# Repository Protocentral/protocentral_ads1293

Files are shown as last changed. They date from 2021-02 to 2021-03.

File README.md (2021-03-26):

ProtoCentral ADS1293 breakout board
================================
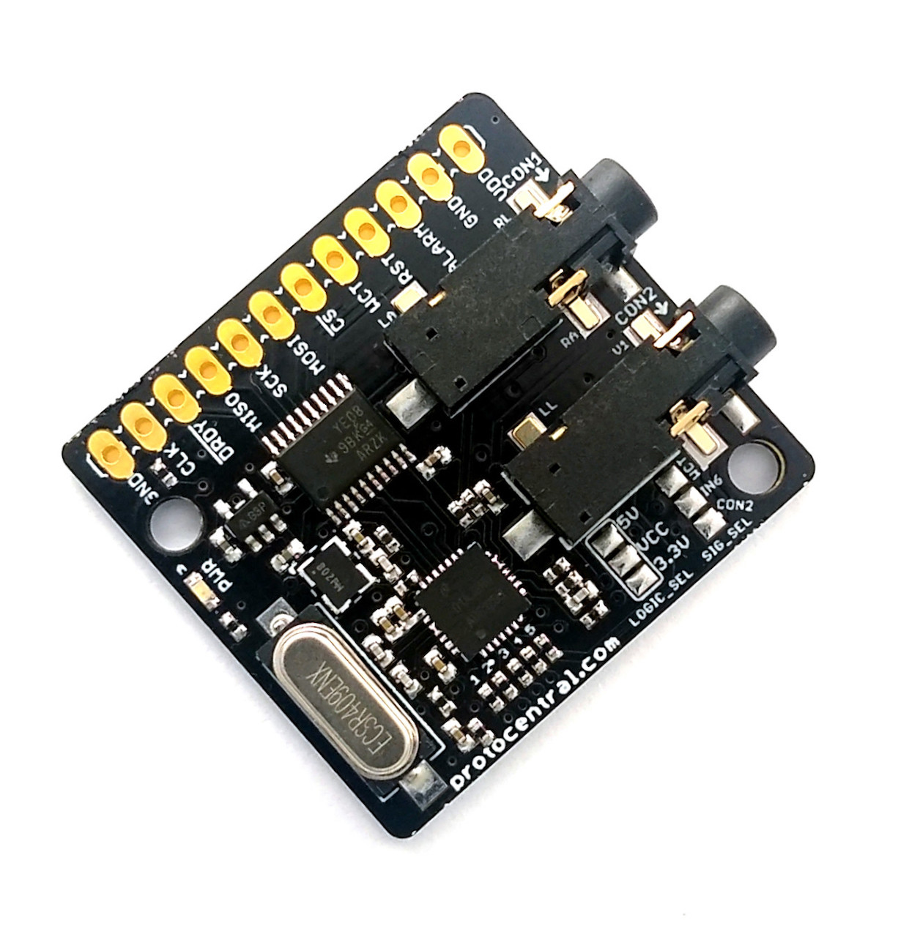
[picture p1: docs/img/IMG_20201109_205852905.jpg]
ADS1293 Breakout


If you don't already have one, you can BUY [ProtoCentral ADS1293 Breakout here.](https://protocentral.com/product/protocentral-ads1293-breakout-board/)

Are you looking for a small ECG board that can read your heart? Well, here it is!!! The ADS1293 breakout board has a capacity of 3 channels and the integration of 4 leads  of the electrical activity of the heart. This is a simple board to connect ECG to your Arduino, Raspberry Pi or any microcontroller you like.

This breakout board for the TI ADS1293 Analog front-end IC comes with with three High-Resolution Digital ECG Channels With Simultaneous PACE Output. 

Features
--------
* ADS1293 Analog Front End IC.
* Three High-Resolution Digital ECG Channels.
* Low Power: 0.3 mW/channel.
* Onboard 3.3V voltage regulator for low noise.
* Onboard logic level translators for Arduino interface.
* Prototyping area for adding additional components.

Includes
--------
* ADS1293 Breakout Board
* 2x Electrode cables with 3.5mm connector
* Pack of disposable stick-on ECG electrodes-20 each

## Wiring to your Arduino

|ADS1293 Pin | Pin Function |Arduino Uno Pin Connection|
|---|:---:|---:|
| DRDY | Data ready Output pin|  D2 | 
| MISO | Slave Out |  D12 |
| MOSI | Slave In |  D11 |
| SCLK | Serial Clock |  D13 |
| CS | Chip Select |  D10 |
| vcc | Digital VDD |  +5V |
| GND | Digital Gnd |  Gnd |

## Running the Arduino Sketch
If you have correctly installed the libraries, the example sketeches should now be available from within Arduino.
If its not showing, please, [Download the Arduino Sketch from our repository here](https://github.com/Protocentral/protocentral-ads1293-arduino) and place it in the arduino libraries folder.

Open up your Arduino IDE and run the Arudino sketch (.ino) file in the archive that you downloaded. Your Arduino should now be programmed to read the ecg data and sending over the USB-UART.

## Using the ProtoCentral OpenView GUI
The GUI for visualizing the ads1293 data is written in Processing, based on Java and is cross-compilable across platforms.

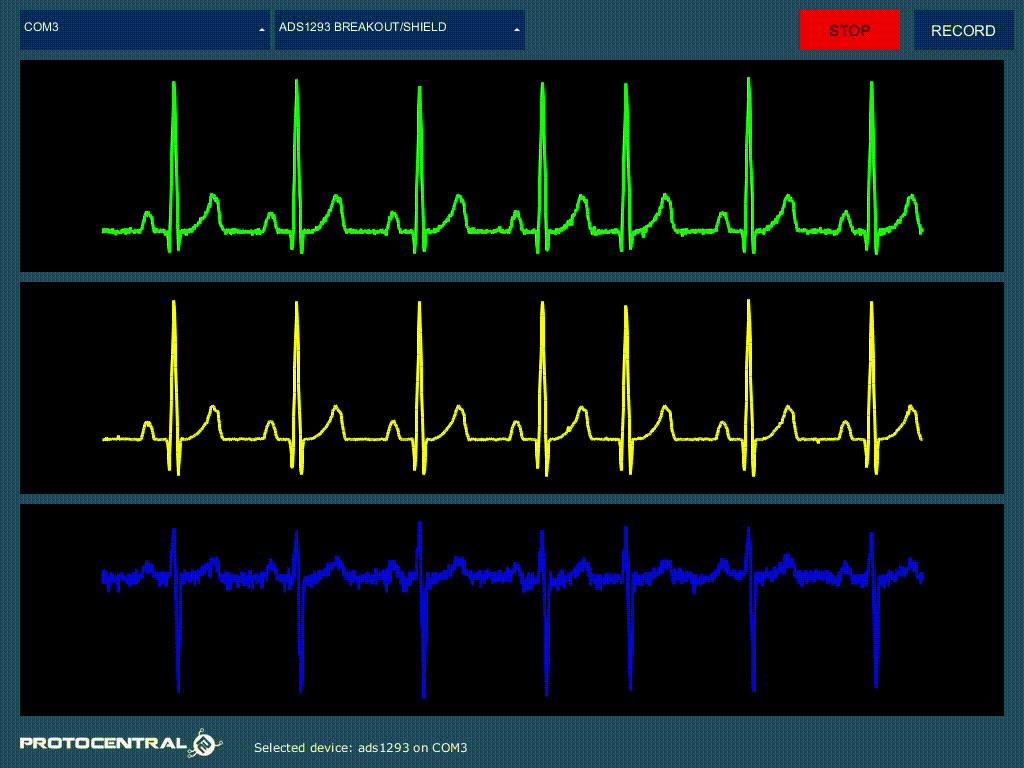
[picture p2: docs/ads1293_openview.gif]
Wearing the Electrode


Java 8 is required on all platforms for running the processing-based GUI application. You can download Java for your platform from the Official Java website.

You can download and install ProtoCentral OpenView from here: https://github.com/Protocentral/protocentral_openview

License Information
===================

ADS1220 Breakout

This product is open source! Both, our hardware and software are open source and licensed under the following licenses:

Hardware
---------

**All hardware is released under the [CERN-OHL-P v2](https://ohwr.org/cern_ohl_p_v2.txt)** license.

Copyright CERN 2020.

This source describes Open Hardware and is licensed under the CERN-OHL-P v2.

You may redistribute and modify this documentation and make products
using it under the terms of the CERN-OHL-P v2 (https:/cern.ch/cern-ohl).
This documentation is distributed WITHOUT ANY EXPRESS OR IMPLIED
WARRANTY, INCLUDING OF MERCHANTABILITY, SATISFACTORY QUALITY
AND FITNESS FOR A PARTICULAR PURPOSE. Please see the CERN-OHL-P v2
for applicable conditions

Software
--------

**All software is released under the MIT License(http://opensource.org/licenses/MIT).**

THE SOFTWARE IS PROVIDED "AS IS", WITHOUT WARRANTY OF ANY KIND, EXPRESS OR IMPLIED, INCLUDING BUT NOT LIMITED TO THE WARRANTIES OF MERCHANTABILITY, FITNESS FOR A PARTICULAR PURPOSE AND NONINFRINGEMENT. IN NO EVENT SHALL THE AUTHORS OR COPYRIGHT HOLDERS BE LIABLE FOR ANY CLAIM, DAMAGES OR OTHER LIABILITY, WHETHER IN AN ACTION OF CONTRACT, TORT OR OTHERWISE, ARISING FROM, OUT OF OR IN CONNECTION WITH THE SOFTWARE OR THE USE OR OTHER DEALINGS IN THE SOFTWARE.

Documentation
-------------
**All documentation is released under [Creative Commons Share-alike 4.0 International](http://creativecommons.org/licenses/by-sa/4.0/).**


You are free to:

* Share — copy and redistribute the material in any medium or format
* Adapt — remix, transform, and build upon the material for any purpose, even commercially.
The licensor cannot revoke these freedoms as long as you follow the license terms.

Under the following terms:

* Attribution — You must give appropriate credit, provide a link to the license, and indicate if changes were made. You may do so in any reasonable manner, but not in any way that suggests the licensor endorses you or your use.
* ShareAlike — If you remix, transform, or build upon the material, you must distribute your contributions under the same license as the original.

Please check [*LICENSE.md*](LICENSE.md) for detailed license descriptions.

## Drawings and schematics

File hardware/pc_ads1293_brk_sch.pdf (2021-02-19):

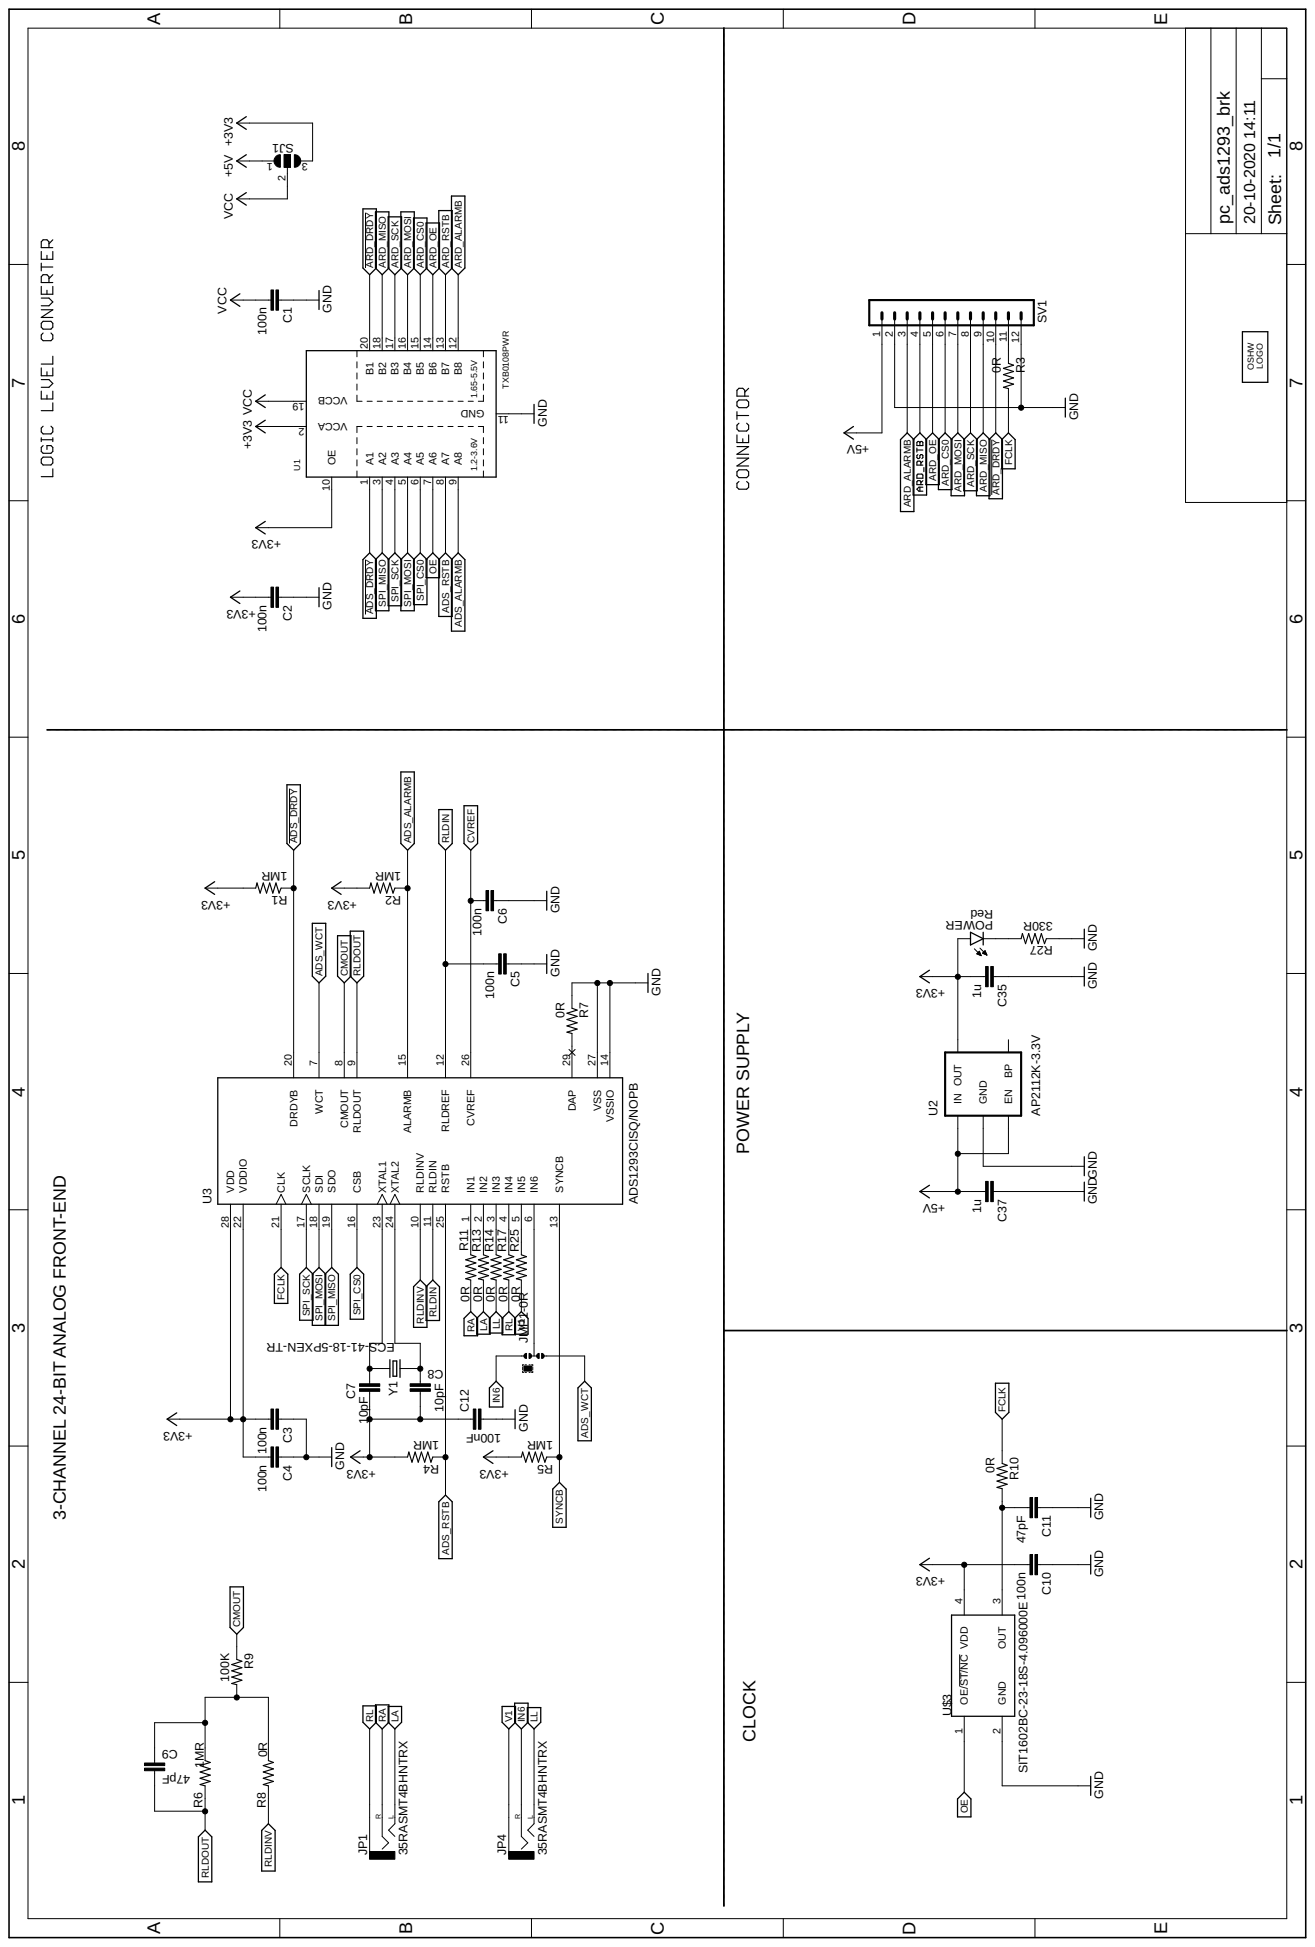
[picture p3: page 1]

1.2-3.6V 1.65-5.5V GND GND 3V3+ GND 1u 1uGND V5+ R033 de R GND V5+ TXB0108PWR +3V3GND 3V3+ 100nGND 100 3V3+ nGND +5V +3V3 VCC VCC VCC AP2112K-3.3V ADS1293CISQ/NOPB 100n 100nGND 3V3+ RM1 RM1 3V3+ 3V3+ 35RASMT4BHNTRX 35RASMT4BHNTRX 100nGND 100nGND GND RM1 RM1 3V3+ 3V3+ RT- NEXP5- 81- 14- SCE 10pF10pF GND 1MR0R Fp74 100K SIT1602BC-23-18S-4.096000E 3V3+ 100nGND GND 47pFGND 0R0R0R0R0R Fn001 0R 0R 0R POWER SUPPLY CLOCK 3-CHANNEL 24-BIT ANALOG FRONT-END C35 C37 72 R RE WOP 123456789101112 SV1 ACCV 2 A1 1 A2 3 A3 4 A4 5 A5 6 A6 7 A7 8 A8 9 DNG 11 BCCV 91 B1 20 B2 18 B3 17 B4 16 B5 15 B6 14 B7 13 B8 12 OE 10 U1 C1 C2 1 3 2 1J S INGN OD UT EN BP U2 IN1 1 WCT 7 CMOUT 8 RLDOUT 9 RLDINV 10 RLDIN 11 SYNCB 13 RLDREF 12 VSSIO 14 ALARMB 15 CSB 16 SCLK 17 SDI 18 SDO 19 DRDYB 20 VDDIO 22 CLK 21 XTAL1 23 RSTB 25 XTAL2 24 CVREF 26 VSS 27 VDD 28 DAP 29 IN2 2 IN3 3 IN4 4 IN5 5 IN6 6 U3 C3 C4 1 R 2 R JP1 JP4 C5 C6 4 R 5 R Y1 C7 8 C R6 R8 9 C R9 OE/ST/NC 1 GND 2 OUT 3 VDD 4 U$3 C10 C11 R11 R13 R14 R17 R25 C12 R7 JMP1-0R R3 R10 ADS_DRDY ADS_DRDY SPI_MISO SPI_MISO SPI_SCK SPI_SCK SPI_MOSI SPI_MOSI SPI_CS0 SPI_CS0 ADS_RSTB ADS_RSTB ADS_WCT ADS_WCT ARD_MOSI ARD_MOSI ARD_MISO ARD_MISO ARD_SCK ARD_SCK ARD_CS0 ARD_CS0 ARD_DRDY ARD_DRDY FCLK FCLK FCLK ADS_ALARMB ADS_ALARMB CVREF RA RA LA LA LL LL RL RL V1 V1 SYNCB RLDINV RLDINV RLDIN RLDIN RLDOUT RLDOUT CMOUT CMOUT ARD_RSTB ARD_ALARMB ARD_ALARMB IN6 IN6 OE OE ARD_OE ARD_OE OSHW LOGO Sheet: ABCDE 1 2 3 4 5 6 7 8 ABCDE 1 2 3 4 5 6 7 8 pc_ads1293_brk 20-10-2020 14:11 1/1 RLRL

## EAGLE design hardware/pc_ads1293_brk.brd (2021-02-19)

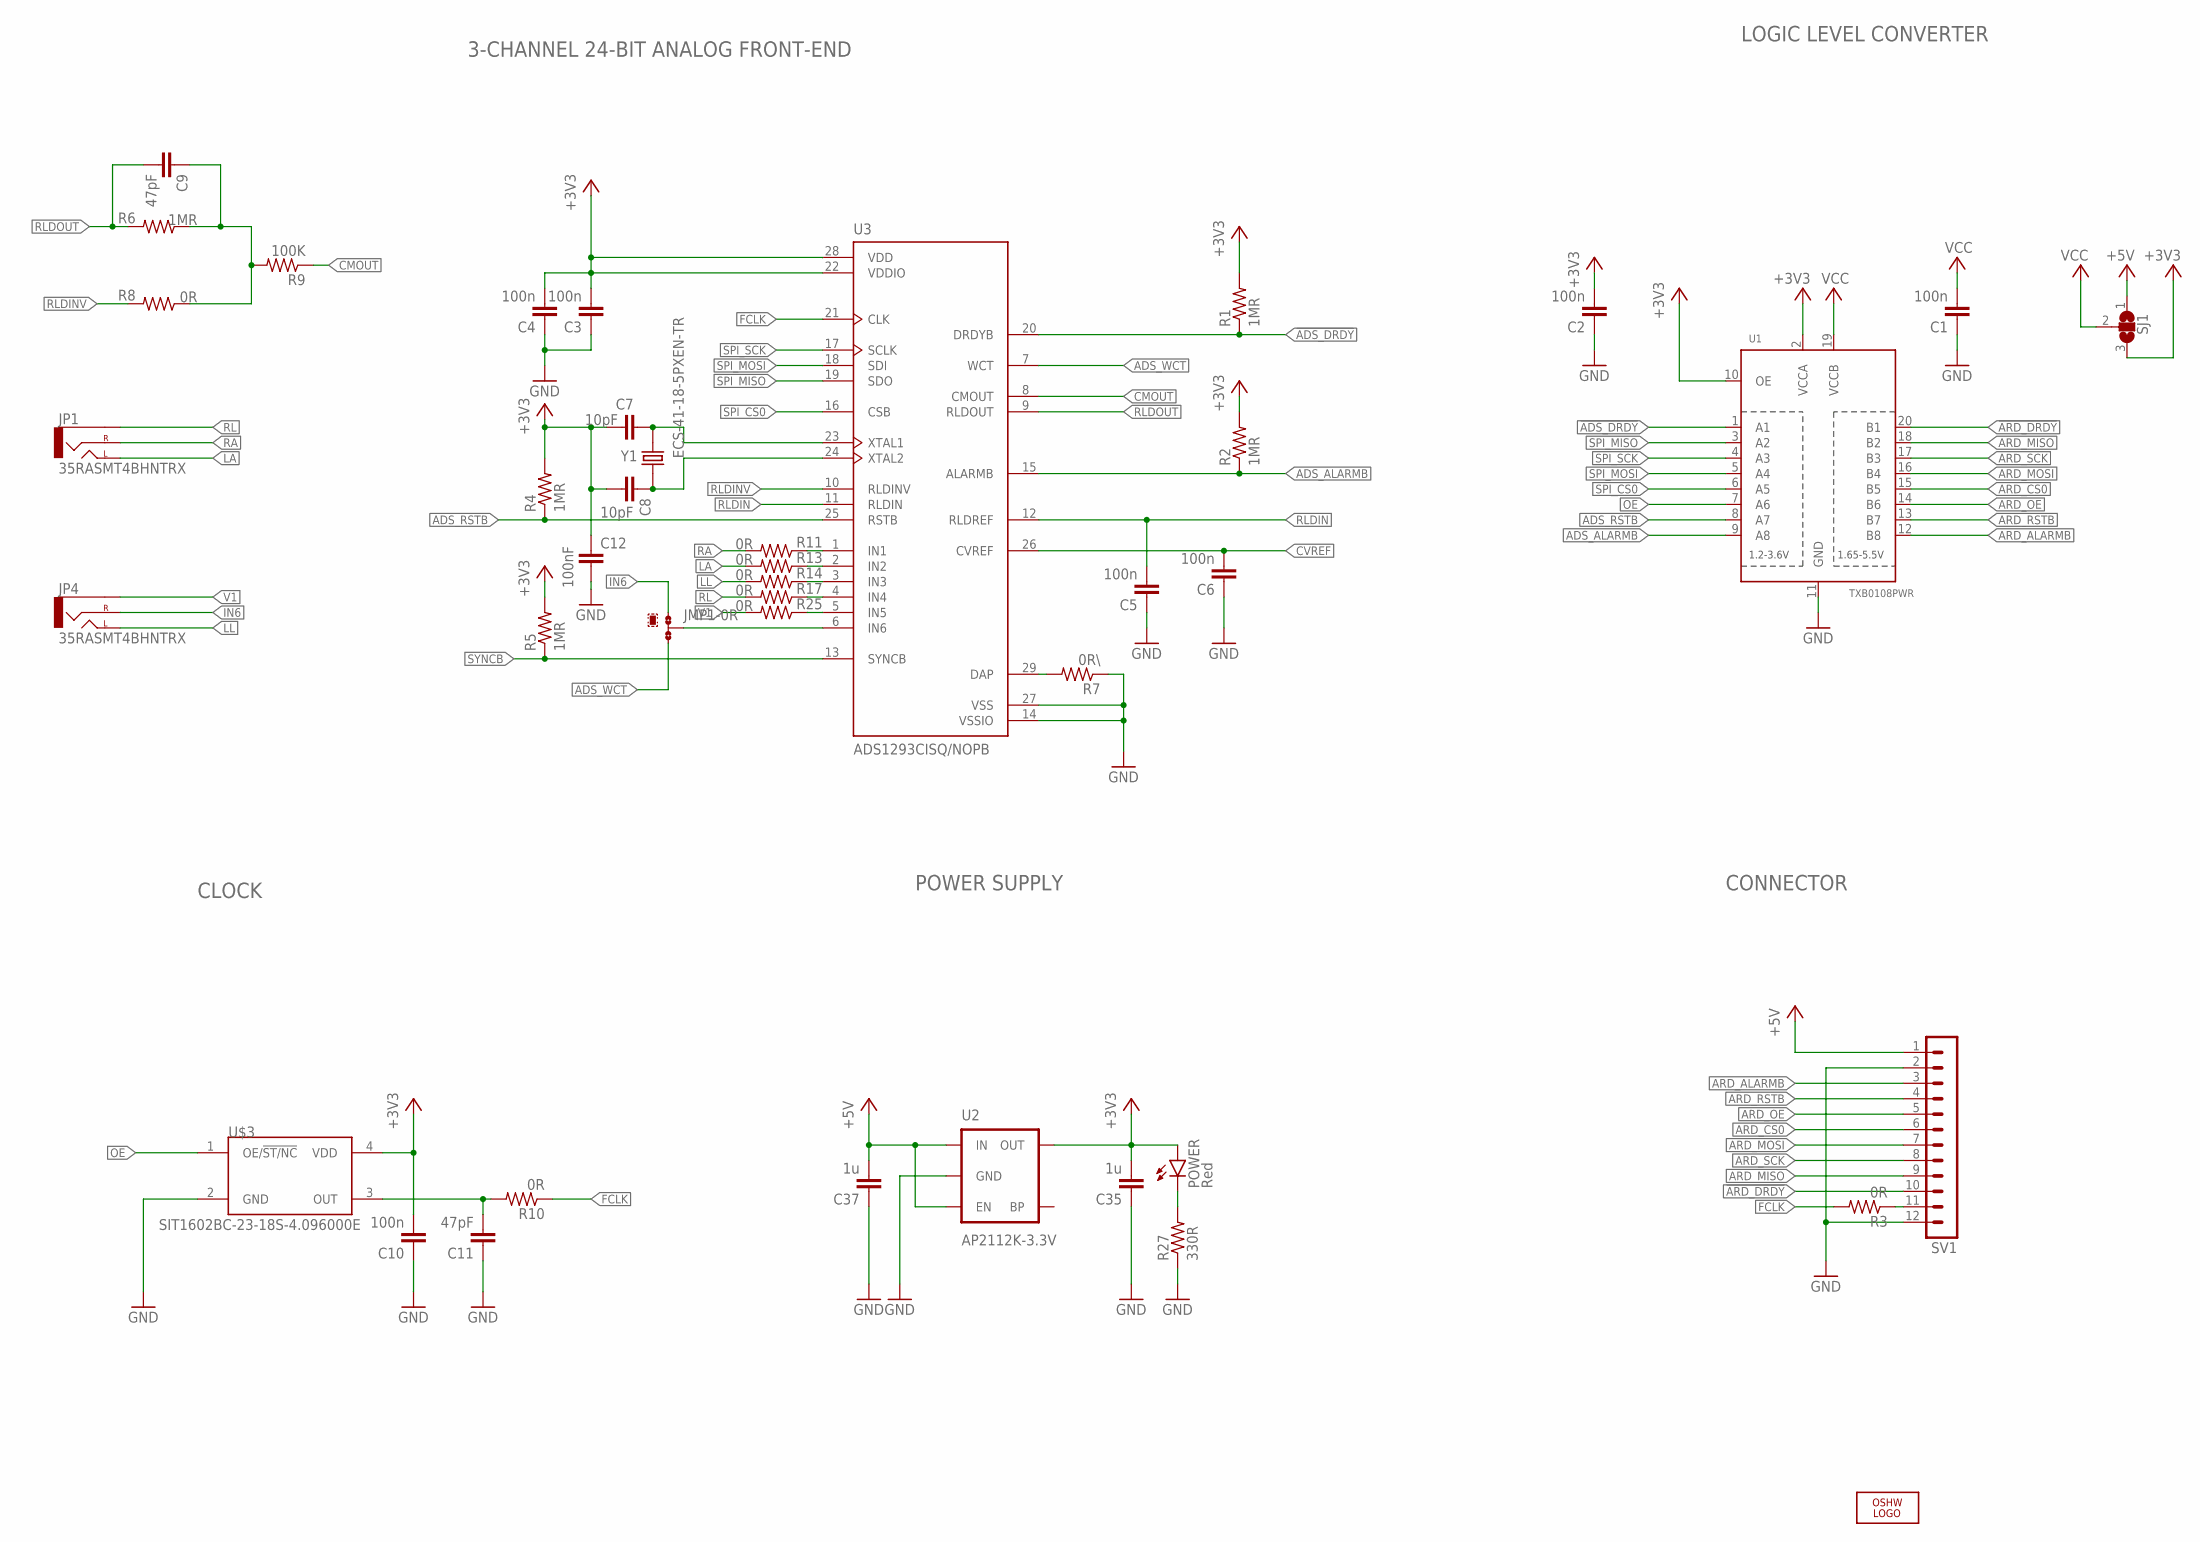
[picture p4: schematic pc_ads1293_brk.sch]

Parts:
C1, C2, C3, C4, C5, C6, C10: 100n; C0402
C7, C8: 10pF; C0402
C9, C11: 47pF; C0402
C12: 100nF; C0402
C35, C37: 1u; C0402
JMP1: 0R-JUMPB; B0R-JMP
JP1, JP4: 35RASMT4BHNTRX; AUDIO-JACK-3.5MM-SMD
LOGO1: OSHW_LOGO_FILLX0100-NT; OSHW_FILLX100_NOTEXT
POWER: Red; CHIPLED_0603
R1, R2, R4, R5, R6: 1MR; R0402
R3, R8, R10, R11, R13, R14, R17, R25: 0R; R0402
R7: 0R\; R0402
R9: 100K; R0402
R27: 330R; R0402
SJ1: SJ2W; SJ_2
SV1: MA12-1
U1: TXB0108PWR; TSSOP20
U2: AP2112K-3.3V; SOT23-5
U3: ADS1293CISQ/NOPB; QFN50P500X500X80-29N
U$3: SIT1602BC-23-18S-4.096000E; SIT1602B
Y1: ECS-41-18-5PXEN-TR; XTAL_ECS-41-18-5PXEN-TR

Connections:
!ADS_DRDY: R1.1, U1.1 (A1), U3.20 (DRDYB)
!ARD_DRDY: SV1.10, U1.20 (B1)
+3V3: C2.2, C3.2, C4.2, C7.2, C8.2, C10.2, C12.1, C35.2, POWER.A, R1.2, R2.2, R4.2, R5.2, SJ1.3, U1.2 (VCCA), U1.10 (OE), U2.5 (OUT), U3.22 (VDDIO), U3.28 (VDD), U$3.4 (VDD)
+5V: C37.2, SJ1.1, SV1.1, U2.1 (IN), U2.3 (EN)
ADS_ALARMB: R2.1, U1.9 (A8), U3.15 (ALARMB)
ADS_RSTB: R4.1, U1.8 (A7), U3.25 (RSTB)
ADS_WCT: JMP1.3, U3.7 (WCT)
ARD_ALARMB: SV1.3, U1.12 (B8)
ARD_CS0: SV1.6, U1.15 (B5)
ARD_MISO: SV1.9, U1.18 (B2)
ARD_MOSI: SV1.7, U1.16 (B4)
ARD_OE: SV1.5, U1.14 (B6)
ARD_RSTB: SV1.4, U1.13 (B7)
ARD_SCK: SV1.8, U1.17 (B3)
CLK: C11.2, R10.2, U$3.3 (OUT)
CMOUT: R9.1, U3.8 (CMOUT)
CVREF: C6.2, U3.26 (CVREF)
FCLK: R3.2, R10.1, U3.21 (CLK)
GND: C1.1, C2.1, C3.1, C4.1, C5.1, C6.1, C10.1, C11.1, C12.2, C35.1, C37.1, R7.1, R27.1, SV1.2, SV1.12, U1.11 (GND), U2.2 (GND), U3.14 (VSSIO), U3.27 (VSS), U$3.2 (GND)
IN6: JMP1.1, JP4.RING (RIGHT)
LA: JP1.TIP (LEFT), R13.2
LL: JP4.TIP (LEFT), R14.2
unnamed: C9.1, R6.1, R8.1, R9.2
unnamed: R11.1, U3.1 (IN1)
unnamed: JMP1.2, U3.6 (IN6)
unnamed: C8.1, U3.24 (XTAL2), Y1.1
unnamed: C7.1, U3.23 (XTAL1), Y1.2
unnamed: R13.1, U3.2 (IN2)
unnamed: POWER.C, R27.2
unnamed: R7.2, U3.29 (DAP)
unnamed: R14.1, U3.3 (IN3)
unnamed: R3.1, SV1.11
unnamed: R17.1, U3.4 (IN4)
unnamed: R25.1, U3.5 (IN5)
OE: U1.7 (A6), U$3.1 (OE/!ST/NC)
RA: JP1.RING (RIGHT), R11.2
RL: JP1.SLEEVE, R17.2
RLDIN: C5.2, U3.11 (RLDIN), U3.12 (RLDREF)
RLDINV: R8.2, U3.10 (RLDINV)
RLDOUT: C9.2, R6.2, U3.9 (RLDOUT)
SPI_CS0: U1.6 (A5), U3.16 (CSB)
SPI_MISO: U1.3 (A2), U3.19 (SDO)
SPI_MOSI: U1.5 (A4), U3.18 (SDI)
SPI_SCK: U1.4 (A3), U3.17 (SCLK)
SYNCB: R5.1, U3.13 (SYNCB)
V1: JP4.SLEEVE, R25.2
VCC: C1.2, SJ1.2, U1.19 (VCCB)

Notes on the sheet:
LOGIC LEVEL CONVERTER
CONNECTOR
POWER SUPPLY
CLOCK
3-CHANNEL 24-BIT ANALOG FRONT-END

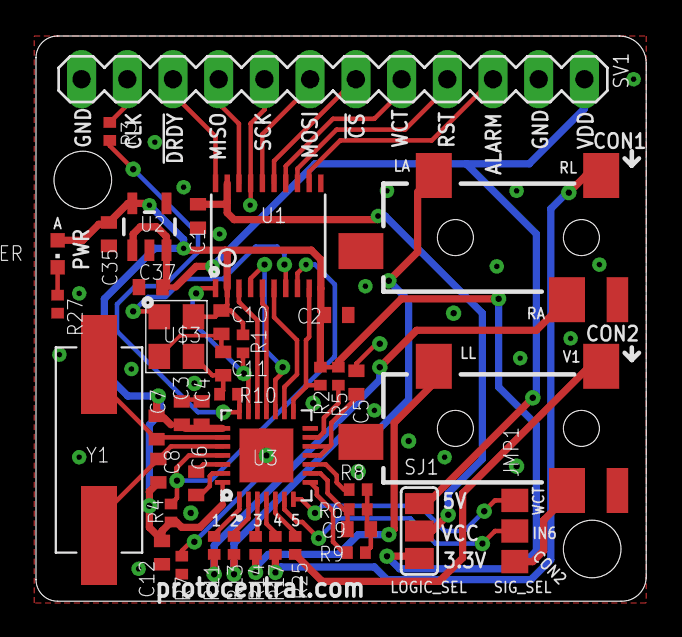
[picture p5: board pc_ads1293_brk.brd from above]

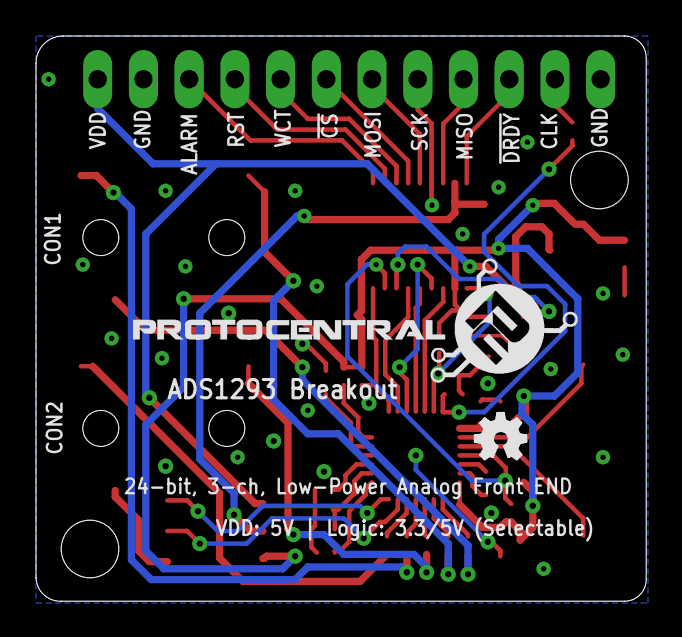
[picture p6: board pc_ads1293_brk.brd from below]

Board: 4 copper layers, 33.9 x 31.4 mm, 43 parts (2 on the bottom side), 47 nets.

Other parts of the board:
U$2: PROTY_WITH_TEXT

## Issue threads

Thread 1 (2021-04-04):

Some design questions

wkraft-fablabka, 2021-04-04:
Hello,
I am looking to your ADS1293 breakout and I have some questions about your design:

- What is the reason of the solder jumper SIG_SEL ? The connection between the Wilson Control Terminal can be done in software, setting the WILSONINT-bit to 1 in WILSON_CN (address 0x10), see figure 48 in the datasheet. With a soldered jumper you may run in problems and you will lose software reconfiguration.
- What is the reason for the additional oscillator on the board? Reading the datasheet, the ADS1293 generates the needed clock with an internal oscillator, supported from the external crystal and capacitors. The clock-pin can be used for two purposes, when cascading multiple ADS1293. The main chip configures clock as output, while the daughter chips getting synchronized clock, using the clock pin as input.  It looks like, that I can't cascade your boards, without unsoldering the additional clock source.
- Furthermore you have two 10pF capacitors close to the crystal, while the datasheet asks for 20pF each. What is the reason for this decision?
- Having a logic level converter on board looks like a perfect solution towards the Arduino solutions. With the possibility for two voltages, why you have no solder jumper on VSS to allow 5V, if available.  As the recommended analog supply voltage should be between 2.7 and 5.5V, it would be nice, to use the wider range, if a second voltage is available.
- Why is SYNCB not available as a pin? This is also needed for cascading multiple boards.

biswaitc127, 2022-06-16:
I am also looking for the answers to the same questions

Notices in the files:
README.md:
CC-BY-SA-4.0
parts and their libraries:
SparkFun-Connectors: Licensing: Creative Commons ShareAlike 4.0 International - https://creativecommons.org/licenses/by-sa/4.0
